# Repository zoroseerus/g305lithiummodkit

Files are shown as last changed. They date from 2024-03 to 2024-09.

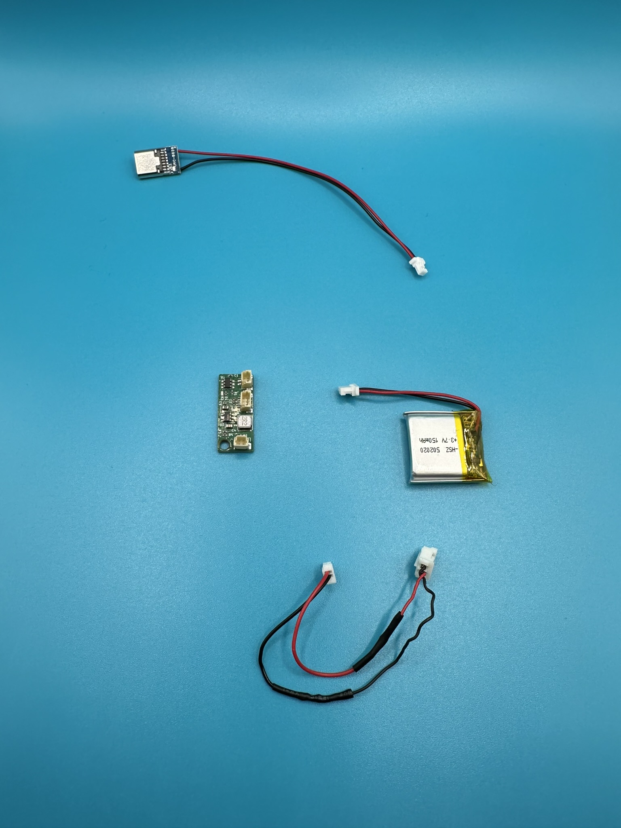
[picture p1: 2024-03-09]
pics/IMG_1835.JPEG

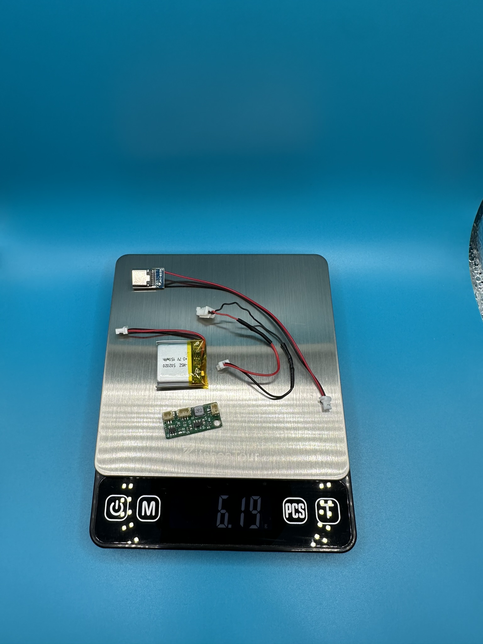
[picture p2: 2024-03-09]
pics/IMG_1836.JPEG

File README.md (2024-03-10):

# g305lithiummodkit
a modkit for the Logitech G305 so you can use lithium batteries and save some weight

Hi there,

Some time ago, enncoo sort of dropped off and nobody is sure what happened to them. As such there's been a hole that their modkit served, so I paid somebody to reverse engineer it on fiverr (@duca99, https://www.fiverr.com/duca99?source=gig_page) so this could be remedied. It seems right to release the files since it's not my design. Hopefully this helps someone.

If you're just interested in buying the modkits, I'll be selling those on https://www.etsy.com/listing/1679779226/logitech-g305-modkit-for-weight , but you can also take these files to a site to make them *queue PCBWAY sponsor segment of the video... wait this isn't YouTube. I digress*. 

I'm uploading the files on here as I was given them, as I'm pretty unfamiliar with PCB design and github such. If there's a signiciantly better way to group them or such feel free to let me know and I can re-arrange things as needed.

I'm under the impression that any (correctly pinned) 3.7V lithium ion batteries should work with it. my example photos are with a 150mAh one as it's a decent size while not being particularly massive, but you can go smaller or larger as desired I believe.

simplified diagram of how it's hooked up:


used in a mice:




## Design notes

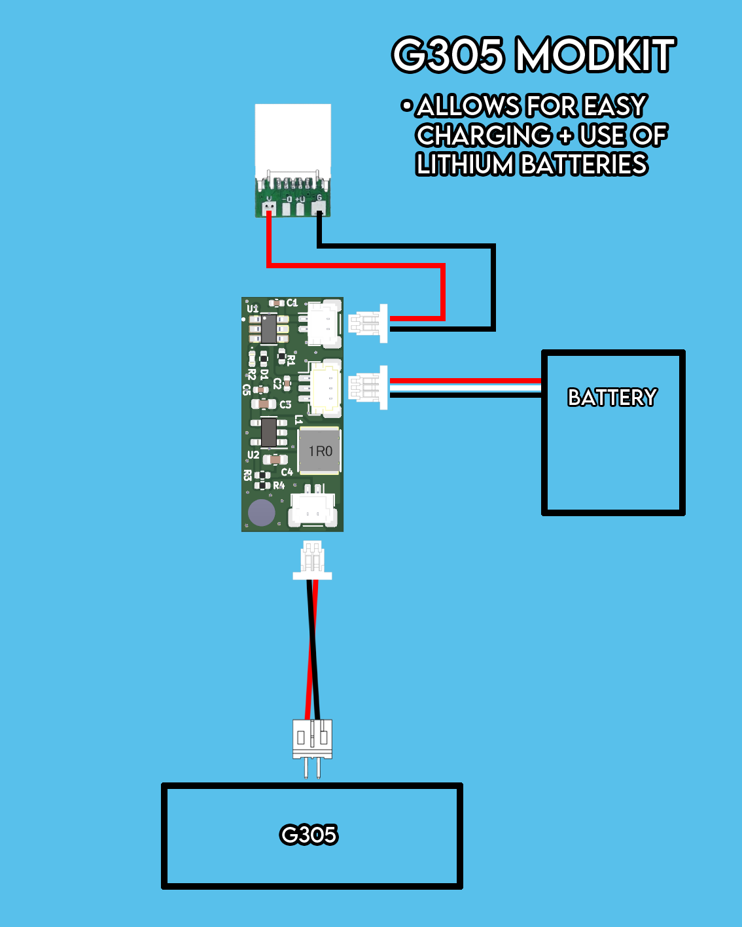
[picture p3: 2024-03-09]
simplifieddiagram.png

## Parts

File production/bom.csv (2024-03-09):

Designator | Footprint | Quantity | Value | LCSC Part #
C1, C2, C5 | 402 | 3 | 1uF | C326568
C3 | 603 | 1 | 4.7uF | C277476
C4 | 603 | 1 | 22uF | C109447
D1 | 402 | 1 | LED | C434449
J1 | JST_SH_BM03B-SRSS-TB_1x03-1MP_P1.00mm_Vertical | 1 | Conn_01x03 | C160389
J2, J3 | JST_SH_BM02B-SRSS-TB_1x02-1MP_P1.00mm_Vertical | 2 | Conn_01x02 | C160388
L1 | INDP4040X180N | 1 | 2.2uH | C167825
R1 | 402 | 1 | 1K | C106235
R2 | 402 | 1 | 1.5K | C105872
R3 | 402 | 1 | 300K | C138011
R4 | 402 | 1 | 200K | C114763
U1 | SOT95P280X145-6N | 1 | BQ21040DBVR | C202311
U2 | SOT-23-5 | 1 | TLV62569DBV | C141836

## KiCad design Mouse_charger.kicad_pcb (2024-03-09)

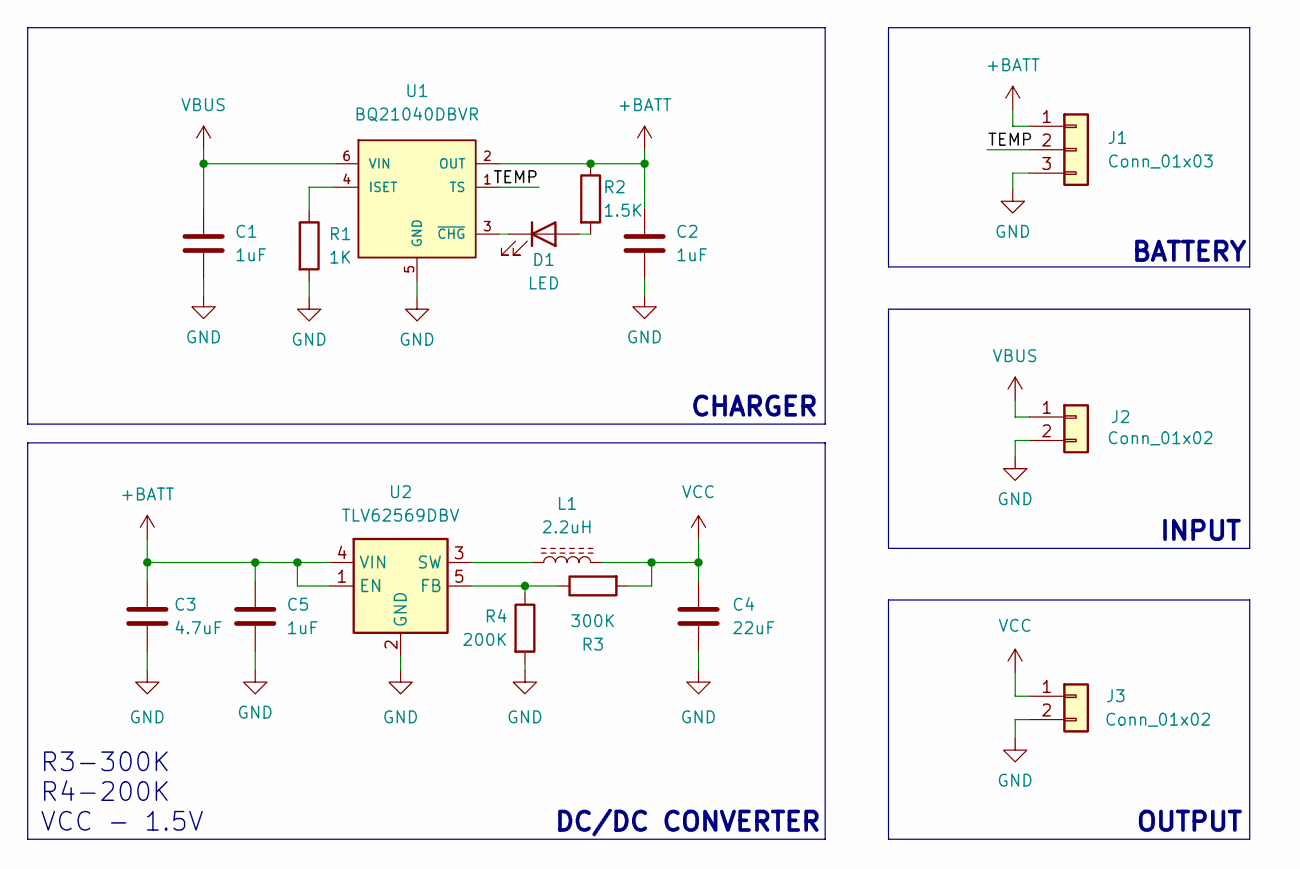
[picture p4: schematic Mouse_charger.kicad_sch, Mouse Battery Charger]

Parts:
C1, C2, C5: 1uF; C_0402_1005Metric
C3: 4.7uF; C_0603_1608Metric
C4: 22uF; C_0603_1608Metric
D1: LED; LED_0402_1005Metric
J1: Conn_01x03; JST_SH_BM03B-SRSS-TB_1x03-1MP_P1.00mm_Vertical
J2, J3: Conn_01x02; JST_SH_BM02B-SRSS-TB_1x02-1MP_P1.00mm_Vertical
L1: 2.2uH; INDP4040X180N
R1: 1K; R_0402_1005Metric
R2: 1.5K; R_0402_1005Metric
R3: 300K; R_0402_1005Metric
R4: 200K; R_0402_1005Metric
U1: BQ21040DBVR; SOT95P280X145-6N
U2: TLV62569DBV; SOT-23-5

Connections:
+BATT: C2.1, C3.1, C5.1, J1.1, R2.1, U1.2 (OUT), U2.1 (EN), U2.4 (VIN)
/TEMP: J1.2, U1.1 (TS)
GND: C1.2, C2.2, C3.2, C4.2, C5.2, J1.3, J2.2, J3.2, R1.2, R4.2, U1.5 (GND), U2.2 (GND)
unnamed: D1.2 (A), R2.2
unnamed: D1.1 (K), U1.3 (~CHG)
unnamed: R1.1, U1.4 (ISET)
unnamed: R3.1, R4.1, U2.5 (FB)
unnamed: L1.1, U2.3 (SW)
VBUS: C1.1, J2.1, U1.6 (VIN)
VCC: C4.1, J3.1, L1.2, R3.2

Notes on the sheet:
BATTERY
R3-300K R4-200K VCC - 1.5V
OUTPUT
DC/DC CONVERTER
INPUT
CHARGER

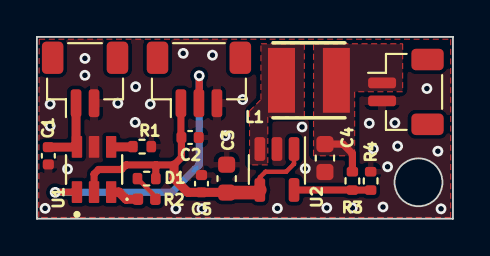
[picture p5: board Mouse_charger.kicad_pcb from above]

Board: 2 copper layers, 23.1 x 10.1 mm, 16 parts (0 on the bottom side), 10 nets.

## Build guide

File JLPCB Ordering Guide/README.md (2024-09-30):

[Google Docs Link](https://docs.google.com/document/d/1lXlm5Rkuk57U9H8ZfG8ebI7v9hPCBv__bzJ77-HJGrs/edit?usp=sharing)

Here’s how I went about ordering PCBs off of JLCPCB for the modkit. You may be able to change settings on it to save money or produce a better PCB, I’m wholly inexperienced in this aspect and am happy to receive any feedback on doing so.

NOTE: For at least a few months JLCPCB has been out of two components. Designation C3/LSCS Part# C277476 can be swapped to C19666 and Designation C4/LSCS Part# C109447 can be swapped to C59461. Maybe they'll be in stock for you to order without substitution.


image (1)
image (2)
image (3)
Now select PCB assembly
image (4)
image (5-2)
The placements will look like this:
image (6)
image (7)
The top line is for the PCBs, the bottom line is for assembly services

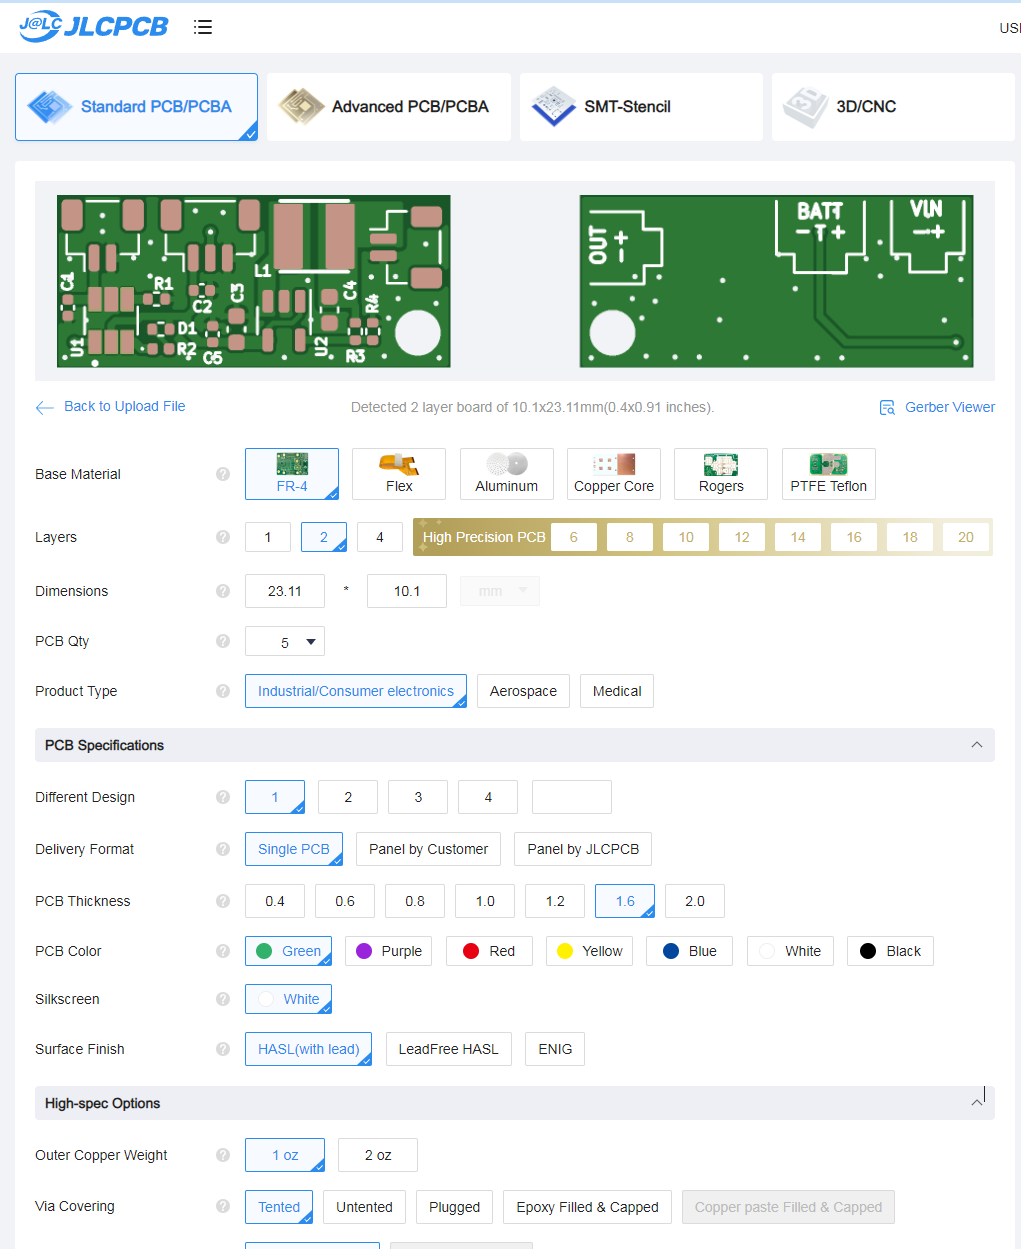
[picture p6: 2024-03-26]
JLPCB Ordering Guide/image (2).png

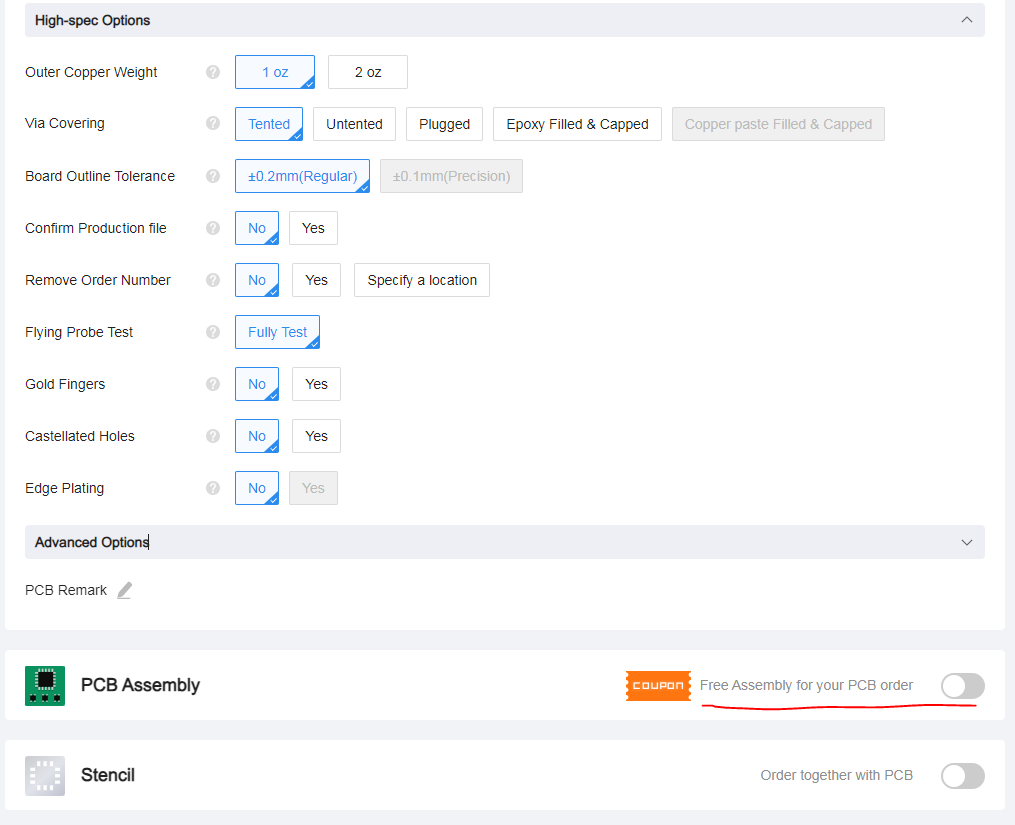
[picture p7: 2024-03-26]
JLPCB Ordering Guide/image (3).png

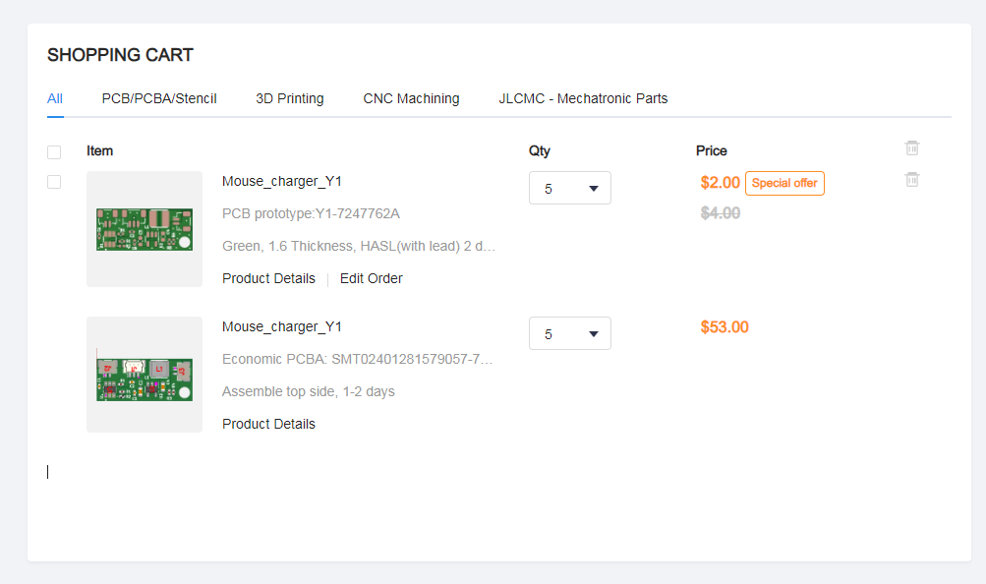
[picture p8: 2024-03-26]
JLPCB Ordering Guide/image (7).png
